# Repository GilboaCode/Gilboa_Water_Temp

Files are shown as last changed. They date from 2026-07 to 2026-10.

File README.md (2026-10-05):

Git and GitHub are used on all files within Gilboa_Water_Temp. After a file is modified:

Save changes to your local directory (your directory should be identical to the one above).

Stage all files.

Commit the files with a message.

Within GitHub, select the “Release” function.

Enter a tag name of the next release number (i.e. Release_4).

Enter a release name of the “release number – Receiver version number – Sender version number” (i.e.  “Release 4 - Receiver v1.3.02 - Sender v1.2.03”).

Attach the binaries (firmware.bin) for the Receiver and Sender. Renaming them with their corresponding target (Receiver_firmware.bin and Sender_firmware.bin).

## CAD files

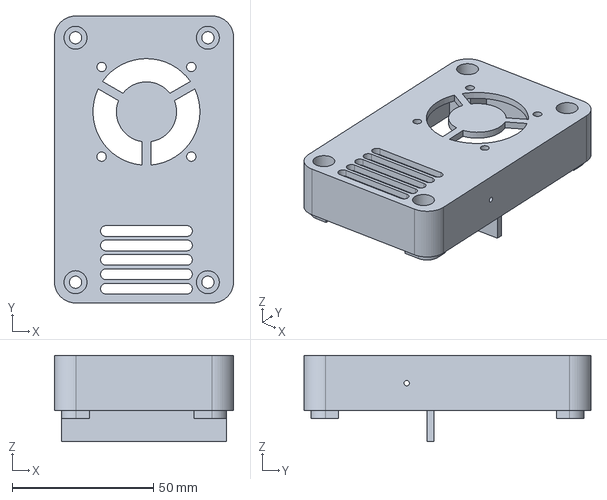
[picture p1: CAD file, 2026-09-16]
Freecad/ Receiver/Receiver.FCStd
63.5 x 101.6 x 30.4 mm

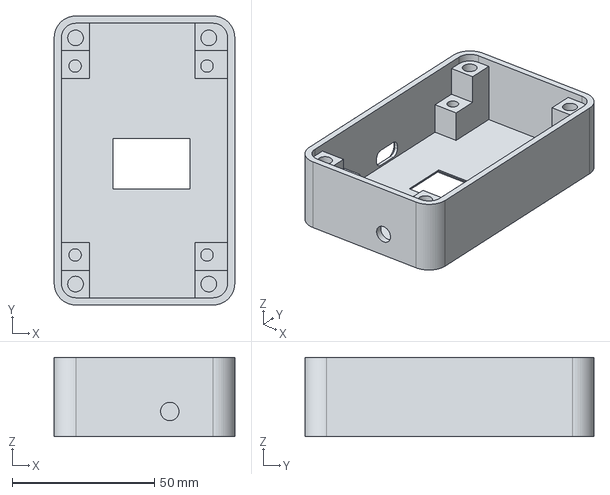
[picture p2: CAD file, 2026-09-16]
Freecad/ Receiver/Step Files/Receiver-Case.step
63.5 x 101.6 x 27.9 mm

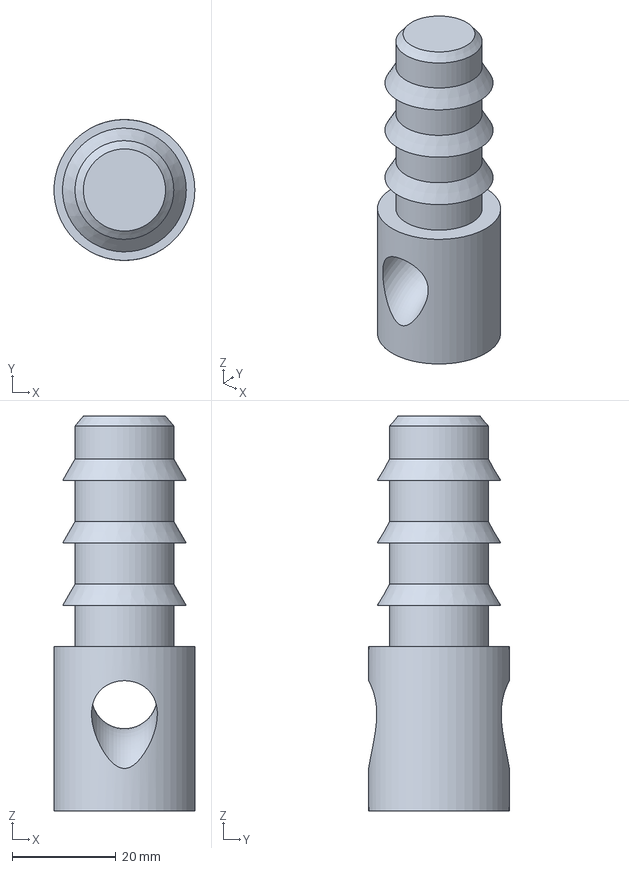
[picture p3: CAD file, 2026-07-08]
Freecad/Barbed_End_Cap_With_Hole/Barbed_End_Cap_With_Hole.FCStd
27.2 x 27.2 x 76.2 mm

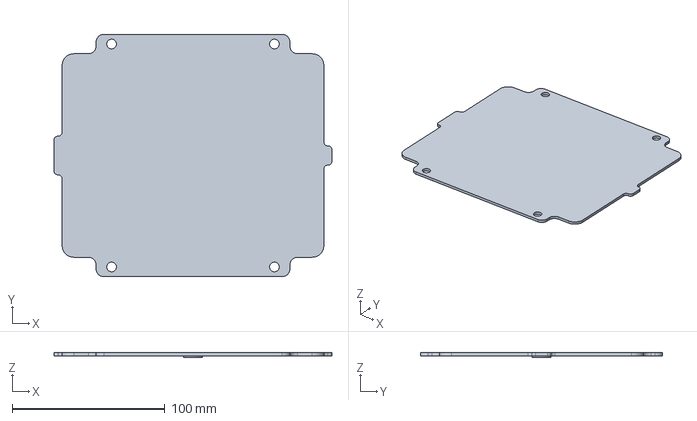
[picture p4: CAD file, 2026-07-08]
Freecad/Sender/Sender Case.FCStd
182.1 x 158.8 x 3.00 mm

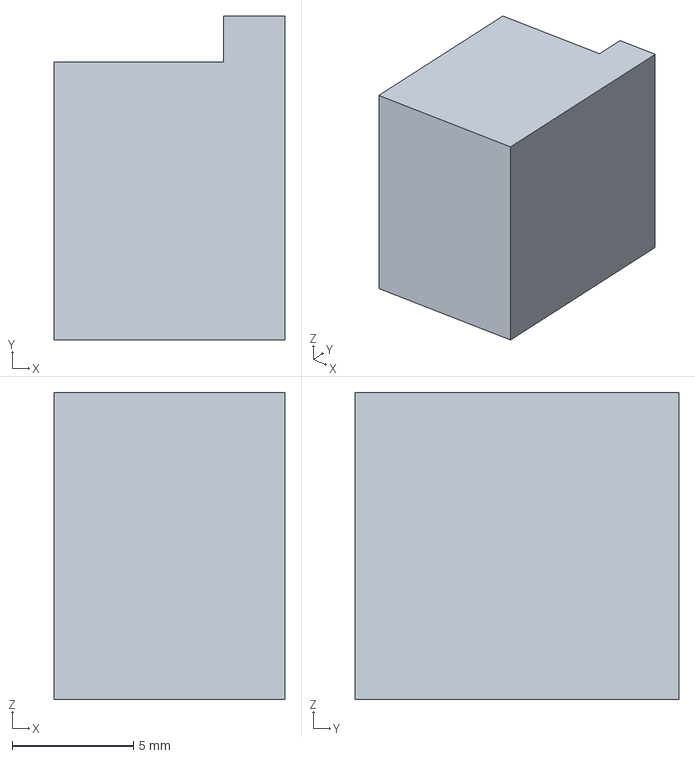
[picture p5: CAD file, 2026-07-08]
Freecad/Solar_Charger_Board_Standoff/Solar_Charger_Board_Standoff.FCStd
9.53 x 13.4 x 12.7 mm

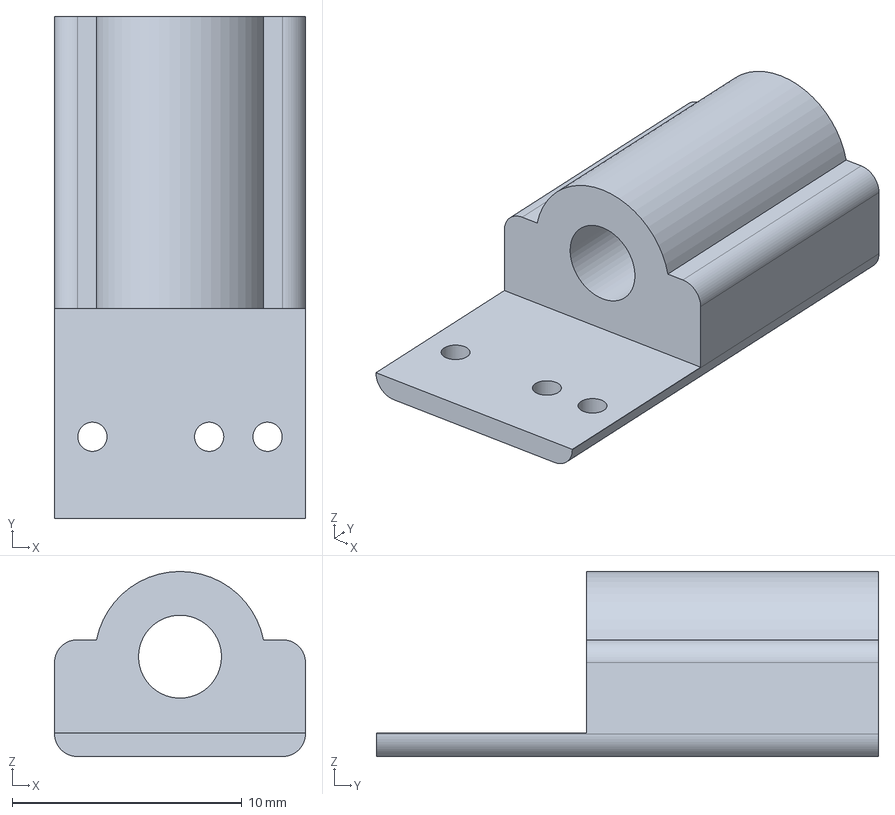
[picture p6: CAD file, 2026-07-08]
Freecad/Transducer_Tube/Transducer_Tube.FCStd
10.9 x 21.8 x 8.05 mm

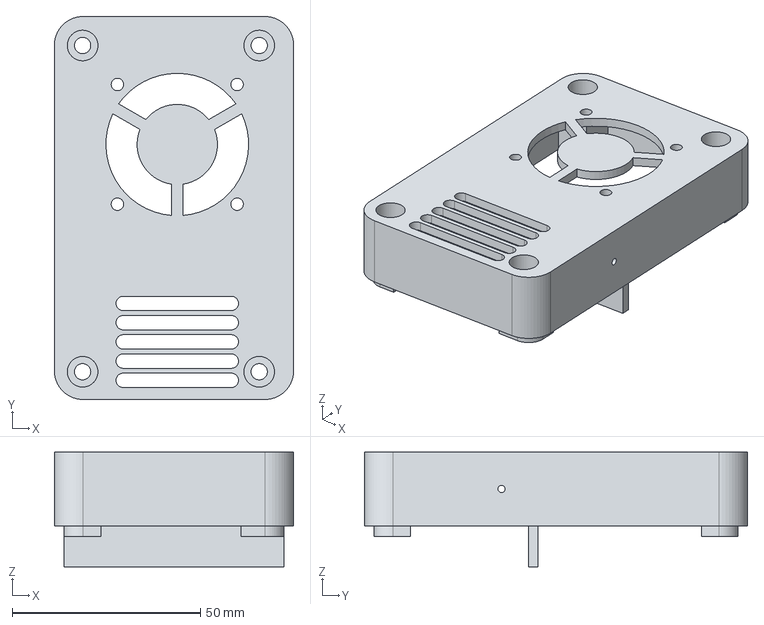
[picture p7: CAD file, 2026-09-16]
Freecad/ Receiver/Step Files/Receiver-Back with Fan.step
63.5 x 101.6 x 30.4 mm

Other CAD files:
Freecad/ Receiver/Step Files/Receiver-Back with Fan.3mf

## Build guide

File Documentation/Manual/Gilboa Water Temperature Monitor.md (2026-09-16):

# Gilboa Water Temperature Monitor

## Receiver Program Structure

```mermaid
flowchart TD
   c((LoRa Recieve interupt))-->d[[LoRa data receive handler]]

   e(CORE 0)-->f[[LoRaTask \nhandle all LoRa processing]]
   e-->g[[System Support \nWiFi, Bluetooth,FreeRTOS scheduler]]

   h(CORE 1)-->i[[Loop]]
   h-->j[[ProcessTask]]
```

## RECEIVER

### Setting up the WiFi Connection of the Receiver

1. Power up the Receiver.
2. If the Receiver has not been given an IP address from the Server, a screen will appear on the Receiver display. The last line will show the IP address the Receiver is using for it's local AP IP address. Record this address.
3. On a PC that is already connected to the WiFi network, change the WiFi connection to the Receiver temporary WiFi SSID **"WaterGaugeReceiver"** with the password:

   ```
   password123
   ```

4. In a browser window on a PC, enter this local AP IP address and a WiFi Manager screen will appear.

5. Press **Configure WiFi**.
6. If a list of networks is displayed:
   - Select the appropriate network.
   - Enter the SSID and password.
   - Save the settings.
7. Once the Receiver accepts the new network credentials, it will obtain an IP address from the selected network.
8. The assigned IP address will be displayed on the Receiver display.

---

### WiFi Reset Button

A WiFi reset button is located on the back of the Receiver.

To reset:

1. Insert a small tool (such as a toothpick) through the access hole.
2. Press until the display indicates that a WiFi reset has occurred.
3. Repeat the **Setting up the WiFi Connection of the Receiver** procedure above.

---

# Water Detected Alarm

The temperature probes are located inside a sealed vinyl tube extending from the surface to **130 feet** underwater.

The tube keeps the electronics dry.

At the bottom of the tube are two water sensors:

- **Lower sensor** — warning sensor
- **Upper sensor** — final alarm sensor (approximately 2 inches above the lower sensor)

When water reaches either sensor:

1. The sensor notifies the Sender located at the surface.
2. During its normal wake-up cycle the Sender transmits the alarm to the Receiver.
3. The Receiver sends an email or text message to every address listed in the **CONFIG** screen.

---

## Sending Text Messages by Email

Use the following email-to-SMS gateway addresses.

| Carrier | Address |
|---|---|
| AT&T | `1234567890@txt.att.net` |
| Verizon | `1234567890@vtext.com` |
| Verizon (messages over 160 characters) | `1234567890@vzwpix.com` |
| T-Mobile | `1234567890@tmomail.net` |
| Sprint | `1234567890@messaging.sprintpcs.com` |

---

# Sender and Receiver Communication

After waking from sleep, the Sender performs the following sequence.

## 1. Send Temperature

Format

```text
T,<thermocouple ROM>,<temperature °F>
```

Example

```text
T,28 DB A7 B1 00 00 00 5E,37.2
```

---

## 2. Delay

```
200 ms
```

---

## 3. Send Sender Status

Format

```text
D,<battery voltage>,<version>,<minutes asleep>,<sleep setpoint>,
<OLED enabled>,<reserved>,<bottom water sensor>,<top water sensor>
```

Example

```text
D,4.08,v1.2.01,10,0,0,0,N,N
```

---

## 4. Delay

```
200 ms
```

---

## 5. Send Complete Command

```text
C
```

---

## Receiver Response

The Receiver replies with:

```text
V,<sleep time>,<OLED disable>,<debug>
```

Example

```text
V,20,0,0
```

---

# Water Detection Email Recipients

If either of these values is received as **Y**:

- Water detected at bottom pins
- Water detected at top pins

the Receiver immediately sends notifications to every recipient in the **Water Detection Email Recipients** list on the configuration screen.

---

# Thermocouple Failure Detection

## Individual Sensor Failure

If a thermocouple fails but the OneWire bus is still operating, that thermocouple reports a **negative temperature**.

---

## OneWire Bus Failure

If the OneWire communication bus fails:

- No thermocouples can be read.
- The Receiver sends a fault message to the primary contact.
- The message reports that the **OneWire bus has faulted**.
- When the fault is corrected, another message is sent containing the restored temperatures.

---

# Telegram Setup

Install the free Telegram application.

Search for and connect to:

```
Gilboa_WaterTemp_bot
```

This allows monitoring the Receiver remotely instead of using the local WiFi interface.

---

## Telegram Commands

### `/status`

Displays:

- Receiver IP address
- Sender temperatures (air temperature plus every 10 ft)
- Sender battery voltage
- Sender version
- Sender CPU temperature
- Sender watchdog counter (current/previous)
- Sender watchdog enabled state
- Sleep timer status
- Receiver version
- Receiver CPU temperature
- Water detection status
- HTTP status code from the last POST request
- Sender OLED mode
- Sender debug mode

---

### `/rom`

Displays ROM addresses of every thermocouple.

---

### `/debug-on`

Enable Sender debug mode.

---

### `/debug-off`

Disable Sender debug mode.

---

### `/WDT-on`

Enable Receiver watchdog timer.

---

### `/WDT-off`

Disable Receiver watchdog timer.

---

### `/ota`

Display OTA partition information.

---

### `/_UPDATE`

Downloads and installs the latest firmware from GitHub.

---

### `/_RESET`

Reset the Receiver.

---

### `/help`

Display safe commands.

---

### `/start`

Same as `/help`.

---

### `?`

Same as `/help`.

---

### `/superhelp`

Displays every available command.

---

## Debug Receiver

Ground **GPIO 4** when using the debugging Receiver hardware.

This changes the Telegram bot name to:

```
Gilboa_WaterTemp_Debug_bot
```

allowing debugging without interfering with the production Receiver.

---

# Uploading New Programs to the Sender (WiFi OTA)

1. Be within WiFi range of the Sender.
2. Move the magnetic switch dongle from its storage position to the active position beneath the solar panel.
3. Connect to WiFi:

```
SSID: Gilboa_Sender
Password: Gilboa_Sender
```

4. Open:

```
http://192.168.4.2/update
```

5. Select **Choose File**.
6. Select the desired `.bin` firmware.
7. Press **Update**.
8. The Sender uploads the firmware and automatically reboots.
9. WiFi disconnects during reboot.
10. Move the magnetic switch back to its storage position.

---

# Uploading New Programs to the Receiver Using Android (USB)

Requirements:

- Android device
- ESPFlash application
- USB-C to USB-C cable

## Determine the Active OTA Slot

1. Open Telegram.
2. Connect to:

```
Gilboa_WaterTemp_bot
```

3. Run:

```
/ota
```

4. Note:

- Running partition
- Slot
- Offset

Typical offsets:

```
0x10000
0x340000
```

---

## Flash Firmware

1. Connect the USB cable.
2. Open ESPFlash.
3. Select the **Flash** icon.
4. Choose the firmware `.bin`.
5. Enter the OTA offset.
6. Select the ESP32 device.
7. Set baud rate:

```
115200
```

8. Upload.

ESPFlash can also monitor the serial output using the **Monitor** button.

---

# Uploading New Programs to the Receiver Using GitHub

Remote firmware updates can be performed through Telegram.

1. Connect to:

```
Gilboa_WaterTemp
```

2. Send:

```
/_UPDATE
```

The Receiver will:

1. Download `Receiver_firmware.bin`
2. Flash the firmware
3. Restart automatically

---

# GitHub Repository

Repository name:

```
Gilboa_Water_Temp
```

Directory structure:

```text
Documentation/
Freecad/
KiCAD/
Visual_Studio_Code/
```

| Directory | Contents |
|---|---|
| Documentation | Documentation |
| Freecad | 3D printable designs |
| KiCAD | Schematics |
| Visual_Studio_Code | Sender and Receiver C++ source code |

---

# Creating a New Release

After modifying files:

1. Save changes.
2. Stage all files.
3. Commit with a commit message.
4. In GitHub select **Release**.
5. Create a new tag.

Example:

```text
Release_4
```

6. Enter a release name.

Example:

```text
Release 4 - Receiver v1.3.02 - Sender v1.2.03
```

7. Attach the firmware binaries:

- `Receiver_firmware.bin`
- `Sender_firmware.bin`

Duplicate firmware.bin and rename the uploaded binaries to match these filenames before publishing the release.

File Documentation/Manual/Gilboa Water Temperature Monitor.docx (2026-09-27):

Gilboa Water Temperature Monitor

RECEIVER

Receiver Configuration Data BACKUP and RESTORE

The configuration variables of the Receiver can be backed up with a terminal connected to the USB port.

To back up the data:

- Enter the command BACKUP on a terminal connected to the USB port of the Receiver. There will be no echo of the typed in characters. No need for a return.
- The ESP32 will display all the configuration variables.
- Highlight and copy the information inclusive to the text “ESP32_NVS_BACKUP_V1” and “ESP32_NVS_BACKUP_END”
- Save this in a txt file.

To restore the data to the Receiver:

- Open the desired saved configuration file that was saved through a previous BACKUP command.
- Highlight and copy the information of this file, inclusive of the text “ESP32_NVS_BACKUP_V1” and “ESP32_NVS_BACKUP_END”.
- Enter the command RESTORE on a terminal connected to the USB port of the Receiver. There will be no echo of your typed characters. No need for a return.
- Paste the copied text into the terminal.

SENDER

SENDER and RECEIVER Communication

The SENDER will wake up after sleep time and sample the thermocouples , then perform the following sequence of events:

- Send the temperatures
  - T,<ROM address of thermocouple>,<thermocouple temperature (x.x) in degrees F>
  - i.e. T,28 DB A7 B1 00 00 00 5E,37.2
- Delay 200 msec.
- Send the SENDER data
  - D,<SENDER battery voltage (volts)>,<SENDER software version number>,<SENDER current time asleep (min)>,<SENDER sleep time setpoint (min)(0=default of 30 min.)>, <SENDER OLED (display) active flag>, <Debug active flag setpoint>, <Water detected at the bottom pins (Y,N)>, <Water detected at the top pins (Y,N)>
  - i.e. D,4.08,v1.2.01,10,0,0,0,N,N
- Delay 200 msec.
- Send the complete command.
  - C

The RECEIVER will then respond:

- Send the setpoint variables to the SENDER
  - V, <Sleep time setpoint (min.)>, <OLED disable setpoint flag (0,1)>, < Debug setpoint flag (0,1) >
  - i.e. V,20,0,0

Water Detected Alarm

The temperature probes are located inside a vinyl tube extending from the surface down to 130 feet in the water. The tube is sealed from the water at the bottom. The purpose of the tube is to keep the electronics dry. Inside the tube at the bottom there are two water sensors that monitor if there is a leak within the tube. The bottom water sensor is the 1st warning sensor, two inches above the bottom sensor is the final alarm sensor. When water is detected on either sensor there will be a signal sent to the Transmitter unit located at the surface, which in turn upon normal wake-up scan will send a message to the Receiver located inside the office. The Receiver will then send an E-mail or a text to all addresses on the list in the CONFIG screen (“Water Detection Email Recipients”).

The format for sending a text message should follow the following address format for the different cellular services:

AT&T: 1234567890@txt.att.net

Verizon: 1234567890@vtext.com

Verizon (longer than 160 characters): 1234567890@vzwpix.com

T-Mobile: 1234567890@tmomail.net

Sprint: 1234567890@messaging.sprintpcs.com

Water Detection Email Recipients

When a value of “Y” is received for the values of “Water detected at the bottom pins” or “ Water detected at the top pins” from the SENDER, the RECEIVER will initiate a message transmission to the recipients in the “Water Detection Email Recipients” list on the config screen.

Thermocouple Failure Detection

When a thermocouple fails and the “one_wire” communication line is still operational the temperature value for that thermocouple will be a negative value.

When the failure corrupts the “one_wire” communication line, the controller can not read any of the thermocouples. This failure is detected and will send a message to the primary contact. The message will state that the “one_wire” has faulted. When the fault has been corrected another message will be sent showing the temperatures of the thermocouples.

Telegram Steup

In order to get the latest information from the Receiver on Telegram instead of from the Receiver’s local WiFi connection, you need to install the free app “Telegram”. Once installed search for the chat name of “Gilboa_WaterTemp_bot” and connect.

The following are valid commands and reponces:

/status

Last update time of temperatures from the Sender

Sender Temperature data (Air Temp + every 10 ft)

Sender Version

Sender CPU Temperature

Sender Battery Voltage

Sender WDT counter (current/previous)(watch-dog-timer)

Sender WDT Enabled state

Sleep timer status (running time / set sleep time for sender)

Receiver Version

Receiver CPU Temperature

Water detection status at lower sensor and upper sensor

HTTP Status Code of last POST request to postUrl

Display Mode of Sender (OLED on/off)

Debug Mode of Sender (on/off)

/rom ROM addresses of all the Thermocouples

/disp_on Turn on the Receiver display (the display will turn off after a time delay).

/debug-on Command to enable debug mode on the Sender

/debug-off Command to disable debug mode on the Sender

/WDT-on Receiver’s Watchdog timer on

/WDT-off Receiver’s Watchdog timer off

/ota Show OTA partition information for Receiver

/_UPDATE Command to upload firmware.bin on the Gilboa Github site to the Receiver

/_RESET Reset the Receiver (not shown in help)

/_NETWORK Show the Receiver Network info

/help Command to show safe commands (shown in green)

/start same as /help

? Same as /help

/superhelp Command to show ALL available commands. (shown in green and in blue)

When using the Debugging Receiver hardware, short to ground the GPIO pin 4. This will allow the debugging receiver to use the Telegram bot name of “Gilboa_WaterTemp_Debug_bot” Allowing the debugging Receiver not to interfere with the Telegram messages from the on-site Receiver at Gilboa.

INSTALLING NEW PROGRAMS IN THE ESP32

Uploading New Programs to the Sender by WiFi

To upload a new program to the Sender with out having to disassemble the unit to get at the USB connector, you can use the OTA by WiFi feature programmed into the Sender code.

- Make sure you are within the WiFi proximity of the Sender unit.
- Move the magnetic switch dongel from it’s storage location to the engage location (under the solar panel). This will activate the Server code on the Sender unit.
- Connect to the Sender unit by WiFi by selecting the SSID of “Gilboa_Sender” with the password of “Gilboa_Sender” on your laptop or phone.
- From a web browser, go to the site “192.168.4.2/update”, to connect to the Sender unit.
- Select the “Choose File” button, then select the desired “.bin” file.
- Select the “Update” button. This will upload the selected .bin file and reset tthe Sender. You will loose the WiFi connection when the Sender is reset.
- Your new program has now been installed on the Sender unit.
- Move the magnetic switch dongel back to it’s storage position.

Uploading New Programs to the Receiver by USB using an Android

To upload a new program to the Receiver using the USB connector using an Android running the program ESBFlash.

- Before any binary file can be downloaded to the Receiver by USB, you need to know which slot is currently holding the Receiver program (slot 0 or slot 1). They each have their own starting address. Run the Telegram application on the Android.
- Connect to “Gilboa_WaterTemp_bot.
- Enter the command “/ota”.
- This will display the “Running partition” and it’s associated slot.
- This slot will have an offset (10000 or 340000). Remember this offset.
- Connect a USB-C male to USB-C male cable between the Receiver and the Android.
- Start the ESBFlash program on the Android.
- Select the “Flash” icon at the bottom left hand side of the Android screen.
- Select the bin file to upload by pressing the “+” nect to “Firmware File”, and choice the file to upload.
- A popup box will appear asking for the address where this bin file is to be uploaded to on the Receiver. Enter the offset that was determined above..
- Another popup box will appear as to what device is this bin file to be uploaded to. There will only be one device, select it.
- For the baud rate, enter 115200.
- Select the upload icon.

The ESPFlash application can also monitor the serial USB line by selecting the “Monitor” icon at the bottom right hand side of the Android screen.

Uploading New Programs to the Receiver by Github

UploadIg a new program to the Receiver remotely by using Github and Telegram allows the user to upload to and flash the Receiver with the latest “Released” program.

- From theTelegram application, connect to “Gilboa_WaterTemp”.
- Enter the command “/_UPDATE”.
- This command will upload the program Receiver_firmware.bin from the “Gilboa_Water_Temp” repository, flash and then reset the ESP32.

The location of the “Receiver_firmware.bin” file is in the Github latest release of the Receiver.

Modifing the files in the GitHub Repository

The name of the Repository is “Gilboa_Water_Temp”. The directoy structure is:

Documentation - All documentation

Freecad - Freecad files for all 3d printed objects

KiCAD - Schematics for all electronic circuits

Visual_Studio_Code - All C++ code for the Sender and Receiver

Git and GitHub are used on all files within Gilboa_Water_Temp. After a file is modified:

- Save changes to your local directory (your directory should be identical to the one above).
- Stage all files.
- Commit the files with a message.
- Push to GitHub
- Within GitHub, select the “Release” function.
  - Enter a tag name of the next release number (i.e. Release_4).
  - Enter a release name of the “release number – Receiver version number – Sender version number” (i.e. “Release 4 - Receiver v1.3.02 - Sender v1.2.03”).
  - Attach the binaries (firmware.bin) for the Receiver and Sender. Renaming them with their corresponding target (Receiver_firmware.bin and Sender_firmware.bin).

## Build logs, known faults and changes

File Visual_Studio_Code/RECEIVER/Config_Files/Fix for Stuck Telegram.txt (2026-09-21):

Commands to kill WEBHOOKs

curl "https://api.telegram.org/bot8328269756:AAGSF-JlY4pAeiHQWRxxzP-bReZdUqOJZxY/deleteWebhook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"
curl "https://api.telegram.org/bot8328269756:AAGSF-JlY4pAeiHQWRxxzP-bReZdUqOJZxY/getWebhookInfo"

curl "https://api.telegram.org/bot8820302613:AAHUGMsmcHJNaG1YZnqkC-uzV6Y8-I1HwvA/deleteWebhook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"
curl "https://api.telegram.org/bot8820302613:AAHUGMsmcHJNaG1YZnqkC-uzV6Y8-I1HwvA/getWebhookInfo"

// Gilboa_WaterTemp_Debug_bot - "8328269756:AAGSF-JlY4pAeiHQWRxxzP-bReZdUqOJZxY"
// Gilboa_WaterTemp_bot - "8820302613:AAHUGMsmcHJNaG1YZnqkC-uzV6Y8-I1HwvA"

NO WEBHOOKs
 curl "https://api.telegram.org/bot8328269756:AAGSF-JlY4pAeiHQWRxxzP-bReZdUqOJZxY/getWebhookInfo"
  {
    "ok":true,
    "result":{
       "url":"",
       "has_custom_certificate":false,
       "pending_update_count":0,
       "allowed_updates":["message","edited_message","channel_post","edited_channel_post"]
     }
  }

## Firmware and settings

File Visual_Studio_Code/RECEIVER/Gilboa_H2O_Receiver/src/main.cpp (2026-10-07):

// Receiver -- v1.3.09
//  * Added a new command (/_HISTORY) to the Telegram bot to display the history of the Receiver. 
//    The times of the last received packets were received from the Sender, and when the receiver was reset.
//  * Fixed the Get Date and Time of last update.
//  * After 60 attemts to connect to WiFi, the Receiver will reset itself. This is to prevent the Receiver from being stuck in 
//    a loop trying to connect to WiFi and not being able to recover.
//  * Added a third WiFi connection when the Gilboa or Klopping network can not connect, Jeff's Android Hot Spot.
//  * Added WiFi connection diagnostics to the OLED display to show which network the Receiver is trying to connect to. 
//
// Receiver -- v1.3.08
//  * Added Daylight savings time (DST) detection to the NTP time client to determine if the current time is in DST or not. 
//    This is to allow for the correct time to be displayed on the OLED display and on the Telegram /status command. 
//    The time is displayed in UTC and the offset is calculated based on the current date and time. The offset is then used 
//    to set the time client to the correct time zone.
//  * Added a new command to the configuration web interface to set the DST mode. The selection is made from a dropdown menu.
//    The selection is 0 - No DST, 1 - DST Auto, 2 - DST all year. The default is 1 - DST Auto. The selection is saved in NVS 
//    and loaded on startup.
//
// Receiver -- v1.3.07
//  * Added a time of last update to be displayed on /status command in Telegram.
//
// Receiver -- v1.3.06
//  * Added a new command (/_NETWORK) to the Telegram bot to seperate the network information of the Receiver from the status
//    command. It will display the SSID, IP address, and MAC address of the Receiver. This is to help with determining what 
//    Network the Receiver is connected to and its network details.

// Receiver -- v1.3.05
//  * Added the wifi network name to the Telegram /status command to show which network the Receiver is connected to. 
//    This is to help with determining what Network the Receiver is connected to.

// Receiver -- v1.3.04
//  * Modified the code to turn off the OLED after 30 seconds after power up of the Receiver. This is to prevent the OLED from being on 
//    for long periods of time and heating up the Receiver.
//  * Added new switch at GPIO19 called activateOLEDpb to activate the OLED display on the Receiver for 30 seconds.
//  * Added a command to the Telegram bot to activate the OLED display on the Receiver for 30 seconds (/disp_on)).
//  * Added three command to USB Terminal to BACKUP, RESTORE and PING the NVS data to a file on the SD card. This is to allow 
//    for easy backup and restore of the Receiver configuration data.
//  * Made the SSID and Password fixed in code. On power up it selects between two SSID's and passwords based on the 
//    state of Debug mode input (GPIO4). If GPIO4 is shorted to ground it will use the debug SSID and password, if not 
//    it will use the production SSID and password. The server will select the IP address. This address will show on the
//    OLED display and on the Telegram /status command. The IP address is fixed in code for both the debug and production 
//    SSID's.   

// Receiver -- v1.3.03
//  * Followed the splitting of the "D" packet from the Sender to "D" excluding water detect and "W" for water detect. 
//    Correcting the problem of n/a for water detect due to data being sent to receiver before 1-wire power being turned on.
//  * Added distinction between failed all LORA reception and failed just t/c reception (with messages sent to recipients).
//  * Instead of sending seperate e-mails out, code has been changed to send one e-mail with all listed recipients in as "cc"ed.
//  * On LoRa setup failure, the code will now wait 10 seconds and then restart the ESP32 instead of hanging in a while loop. 
//    This allows for a more robust recovery from LoRa module issues.
//  * In Telegram /status printout, moved Sender version before Sender battery voltage to make it easier to read and understand the 
//    information being displayed.
//
// Receiver -- V1.3.02
//  * Added code to monitor the timing of the "D" packet from the Sender to implement a watchdog. 
//    When the Sender wakes up it will send a "D" packet to the Receiver first, before turning on the aux 3 volts that powers up the 1-wire board.
//    If the Receiver does not receive a "D" packet from the Sender within 60 minutes, it will assume that the Sender is not 
//    functioning and will send an alert to the operator via email (if configured).
//    This will determine if the loss of temperature readings is due to a failure of the 1-wire board or a failure of the Sender itself.
//    A flag is also added to signify the the Receiver has seen the Sender at least one time to handle the power up sequence of the Receiver and Sender.
//    This flag is used to prevent false alerts on the first boot of the Receiver when the Sender has not yet sent a "D" packet.
//    The function of this change is to determine if no t/c data is due to flooded t/c tube or an Sender ESP32 problem.
//    There is a disable flag to disable the watchdog if the operator does not want to use this feature. 
//    The disable flag is settable by the operator and is settable in the Telegram page.
//  * Changed the name of the GitHub download file to Receiver_firmware.bin to distinguish it from the 
//    Sender_firmware.bin file. The Receiver_firmware.bin file is in the "latest" folder of the GitHub repository.
//
// Receiver -- V1.3.01
//  * Modified the location of the firmware.bin to be in the "latest" folder of the GitHub repository to allow for future versioning of the firmware.
//
// Receiver -- V1.3.00
//  * Added a new command (/_UPDATE)to the Telegram bot to update the Receiver remotely. It will download and install the latest firmware from the GitHub repository 
//
// Receiver -- V1.2.05
//  * Added a new command (/_RESET)to the Telegram bot to reset the Receiver remotely. The command is /reset and it will restart the Receiver when issued.*
//  * Moved all the LoRa xmitt/rcve interrupts to a single core.
//
// Receiver -- V1.2.04
//  * Changed the reception of LORA commnication from polling to interrupt based.
//  * Hide the "debug-on" and "debug-off" commands from the Telegram help display, commands are still active.
//
// Receiver -- V1.2.03
//  * Changed text on web site display from "Battery" to "Sender Battery" to clarify that this is the battery voltage of the Sender, not the Receiver. 
//
// Receiver -- V1.2.02
// * Added Telegram Bot integration for:
//  /status command
//      Receiver IP address
//      Sender Temperature data (Air Temp + every 10 ft if detected)
//      Sender Battery Voltage
//      Sender Version
//      Receiver Version
//      Water detection status at top and bottom sensors
//      HTTP Status Code of last POST request to postUrl
//      Sleep timer status (running time / set sleep time for sender)
//      Display Mode of Sender (OLED Active)
//      Debug Mode of Sender
//  /rom  Display the thermocouple ROM addresses
//  /debug-on command to enable debug mode on the Sender 
//  /debug-off command to disable debug mode on the Sender
//  /help command to show available commands
//  * Added Sender and Receiver CPU temperature reading
//  * Added a Debug Telegram bot tolken when a second receiver is being used to debug  new code on the Sender without interfering with the main Receiver bot. 

// Receiver - v1.2.01
// * Added water detection status to the OLED display and the local web page.
// * Added email alert functionality to notify the operator when water is detected at the top or bottom sensor. The email recipient can be configured on the web page.
// *    Gilboa Water Temp project Gmail account
// *    GilboaWaterTemp@gmail.com
// *    Login Password: 87Gil2026 (only for manual login)
// *    App Password: efocbnzvxhcfwngx (app password for this project)
// * Added NTP client to get real time for email alerts and web page display. Time is displayed in UTC.
// * Added ability to configure multiple recipient emails (up to 6) on the web page. These are saved in NVS and loaded on startup.
// * Added ability to configure the sender email and password (app password) on the web page. These are saved in NVS and loaded on startup.

// *

//Receiver - v1.2.00
// * Receive temps from string T,ROM address,temperature
// * Receive data from string D,battery voltage,sender_version,SLEEP_MINUTES
// * After data received from Sender send the string  V,aux_sleep_minutes,OLED_flag_from_receiver,debug_flag_from_receiver
// * Added flag in the Receiver to tell the Sender to enter debug mode.
// * Added the flag to tell the Sender to enter OLED active mode.
// * Added a color change to RED in the "Position" field on the config screen when a thermocouple is not detected.
// * Added red color change to the submit buttons on the config page when there are unsaved changes.
// * Added Sleep time counter and setpoint on the main web page.


// Receiver - v1.1.01 
// • Display "Looking for WiFi" on power up
// * On the local web page display the version number of the Receiver
// * Added HTTP POST for link to web server
// * Added http status code to the OLED display and on the Config web page
// * Removed the 15 seceond refresh rate on the config web page to prevent interference with form submission
// * On the local web page display the version number of the Sender (FUTURE)
// * Added flag to tell the Sender to update every10 seconds for testing (FUTURE)

// Receiver - v1.0.07 (FINAL – GRAPH FIXED + EVERYTHING ELSE PRESERVED)
// • Physical WiFi reset: GPIO45 → GND only
// • No web reset page
// • All temperatures show correctly (including Air Temp)
// • Perfect working temperature vs depth graph

#define receiver_version "v1.3.09"

#include <RadioLib.h>
#include <SPI.h>
#include <U8g2lib.h>
#include <Wire.h>
#include <WiFi.h>
#include <WiFiManager.h>
#include <WebServer.h>
#include <Preferences.h>
#include <HTTPClient.h>
#include <ESP_Mail_Client.h>
#include <ctype.h>
#include <string.h>

#include <NTPClient.h>
#include <WiFiUdp.h>

#include <HTTPUpdate.h>
#include "esp_ota_ops.h"
#include "esp_partition.h"
#include <esp_image_format.h>


// ---------------------------------------
// ---------- IP configurations ----------
// ---------------------------------------

// ---------- WiFi credentials Gilboa Guest ----------
String ssid_pd     = "Gilboa Guest";
String password_pd = "DiveGilboa";

// ---------- Alternate 1 WiFi credentials Gilboa Office ----------
//String ssid_alt1     =  "Office";
String ssid_alt1     =  "OOffice";
String password_alt1 = "FullTank#0412";

// ---------- Alternate 2 WiFi credentials Jeff's Android Hotspot ----------
String ssid_alt2     = "Galaxy S26 Ultra BF31";
String password_alt2 = "z2knwvh3bckrhgs";

// Debug WiFi credentials for testing
String ssid_db     = "k-net";
String password_db = "5f6d35440b39983686af09321d";



// ---------- WiFi credentials ----------
String ssid     = "";
String password = "";

// Telegram Bot
#include <WiFiClientSecure.h>
#include <UniversalTelegramBot.h>
// Gilboa_WaterTemp_Debug_bot - "8328269756:AAGSF-JlY4pAeiHQWRxxzP-bReZdUqOJZxY"
// Gilboa_WaterTemp_bot - "8820302613:AAHUGMsmcHJNaG1YZnqkC-uzV6Y8-I1HwvA"
#define Telegram_Debug_Mode_Pin 4 // Short to ground to enable the Telegram tolken of Gilboa_WaterTemp_Debug_bot tolken
#define BOT_TOKEN "8820302613:AAHUGMsmcHJNaG1YZnqkC-uzV6Y8-I1HwvA"
#define BOT_TOKEN_Debug "8328269756:AAGSF-JlY4pAeiHQWRxxzP-bReZdUqOJZxY"
String Active_Bot_Token = BOT_TOKEN; // Default to the main bot token, can be changed to the debug bot token if the debug mode pin is shorted to ground 
WiFiClientSecure secured_client;
UniversalTelegramBot bot(Active_Bot_Token, secured_client);



// Gmail SMTP Server Settings
#define SMTP_server "smtp.gmail.com"
#define SMTP_Port 465
String sender_email = "GilboaWaterTemp@gmail.com";
String sender_password = "efocbnzvxhcfwngx"; // App password for this project, not the actual email password
#define Recipient_name ""
SMTPSession smtp;


#define LORA_MOSI 10
#define LORA_MISO 11
#define LORA_SCK  9
#define LORA_CS   8
#define LORA_RST  12
#define LORA_BUSY 13
#define LORA_DIO1 14    // Interupt pin for LoRa module, used to detect when a packet is received
#define LORA_FREQ 915.0f

#define OLED_ON_PB 19 // Short to ground to activate the OLED display on the Receiver for 30 seconds
int OLED_On_Timer_Counter = 0; // Timer to track how long the OLED display has been on, in seconds
bool OLED_On_Flag = false; // Flag to indicate if the OLED display is on or off
bool displayOnCommand = false; // Flag to indicate if the display has been commanded to turn on

#define RESET_PIN 45
#define Display_On_Pin 36 //Set GPIO36 LOW before initializing the OLED display (display.begin())
bool resetTriggered = false;

U8G2_SSD1306_128X64_NONAME_F_HW_I2C u8g2(U8G2_R0, 21);
WebServer server(80);
Preferences prefs;

// Graph Y-axis (saved in NVS)
float graphMinY = 32.0f;
float graphMaxY = 90.0f;

String  Recipient_email = "jeffklopping@gmail.com"; // Default recipient email, can be updated on the web page and saved in NVS

String postUrl = "http://jsonplaceholder.typicode.com/test"; // Default POST URL for testing, can be updated on the web page and saved in NVS
int httpCode=0;

// Setup the handle for the two code tasks
TaskHandle_t task0Handle;
TaskHandle_t task1Handle;
// Create the radio object
SX1262 LoRa = new Module(LORA_CS, LORA_DIO1, LORA_RST, LORA_BUSY);
// Global variables for interupt flag
bool shutUpImTransmitting = false;
bool newPacketReceived = false; 
struct LoRaPacket // Buffer for the incomming LoRa data
{
    char text[128];
};
QueueHandle_t loraQueue;
String sendPacket;
int delayTimeBeforeVPacket = 225; // Delay between packets in milliseconds

// Global state
String SenderVersion = "N/A";
int  SenderSleepTime = 0;
String ReceiverVersion = receiver_version;

String lastSenderBatt = "N/A";
String lastRssiStr = "N/A";
unsigned long lastPacketTime = 0;
#define SLEEP_TIMEOUT_MS 20000
int sleep_time_for_sender ;

// Array for up to 6 recipient emails
String recipient_emails[6] = {
  "jeffklopping@gmail.com", "", "", "", "", ""
};

// Real time
WiFiUDP ntpUDP;
NTPClient timeClient(ntpUDP, "pool.ntp.org", 0 , 60000);  // UTC offset 0 hours, update every 60s
int hour;
int minute ;
int second ;
int year;
int month;
int day ;
int UTCoffset;
bool daylight_saving_time_flag ; // True- Enabled, False - Disabled. This is to allow the operator to turn off DST detection if the operator does not want to use this feature. The default is DST detection on. This variable is stored in NVS and is loaded on startup.
int DayLightSavingTimeMode = 0; // 0 = No DST , 1 = DST Auto, 2 = DST all year
#define packetTimeBufferSize 45
String last30PacketTimes[packetTimeBufferSize]; // Buffer of the last packet times received from the Sender
int last30PacketTimesIndex = 0; // pointer to the next index in the last30PacketTimes array to store the next packet time


// Sender Water Detector 
String water_top_detected = "N/A";
String water_bottom_detected = "N/A";
bool topWaterAlertSent = false;    // true = alert already sent for top sensor
bool bottomWaterAlertSent = false; // true = alert already sent for bottom sensor

// Timer to track running time since last packet
unsigned long runningTimer = 0;
int minCounter = 0;

// Variable to handle watchdog of Sender ESP32 to determine if the Sender is alive and functioning properly
// When a "D" packet is received move the runningDataPacketTimer to previousDataPacketTime and runningDataPacketTimer=0. 
// and save millis() in lastDataPacketTime. 
bool senderSeenFlag = false; // Flag to indicate if the Sender has been seen at least once
unsigned long lastDataPacketTime = 0.0; // Real time of the last "D" packet received from the Sender 
unsigned long previousDataPacketTime = 0.0; // Previous measuredtime between "D" packet received from the Sender 
unsigned long runningDataPacketTimer = 0; // Active running timer for "D" packets from the Sender in minutes
static bool senderFailedFlag = false; // Flag to indicate if the Sender has failed to send a "D" packet within the timeout period
bool watchdogEnableFlag = false; // Flag to indicate if the watchdog is enabled by the operator via Telegram bot command
static bool senderThermocoupleFailFlag; // Flag to indicate no t/c data in 60 min.

// Flag to send variables even on no change (startup)
bool resetVariablesFlag = false;
// Operator Variables to send to Sender
static int aux_sleep_minutes=0;
static boolean OLED_flag_from_receiver = false;
static boolean debug_flag_from_receiver = false;
// Operator variables old values for change detection
int old_aux_sleep_minutes=0;
boolean old_OLED_flag_from_receiver = false;
boolean old_debug_flag_from_receiver = false;

String uniqueRoms[14];
int uniqueRomCount = 0;

String romTable[14];
float temperatures[14];
bool romTableLoaded = false;
bool temperatureDetected[14] = {false};
bool temperatureDetectedHistory[14] = {false};
float defaultNoThermocoupleTemp = -196.6f; // Default temp when no thermocouple is connected

const char* depthLabels[14] = {
  "Air   ", "10  ft", "20  ft", "30  ft", "40  ft", "50  ft", "60  ft",
  "70  ft", "80  ft", "90  ft", "100 ft", "110 ft", "120 ft", "130 ft"
};

const int w = 600;
const int h = 300;
const int margin = 50;

// Processor temperatures
float Receiver_temp_farenheit = 0.0f;
String Sender_temp_farenheit ;

// Telegram Bot variables
bool telegramResetFlag = false; // Flag to indicate if the /reset command was received from the Telegram bot
bool telegramUpdateFlag = false; // Flag to indicate if the /update command was received from the Telegram bot
bool telegramUpdateFailedFlag = false; // Flag to indicate if the /update command failed
const char* firmwareURL ="https://github.com/GilboaCode/Gilboa_Water_Temp/releases/latest/download/Receiver_firmware.bin";
bool updateStarted = false;


// === NVS ===
void loadGraphLimits() {
  prefs.begin("graph", true);
  graphMinY = prefs.getFloat("minY", 32.0f);
  graphMaxY = prefs.getFloat("maxY", 90.0f);
  prefs.end();
}

void saveGraphLimits() {
  prefs.begin("graph", false);
  prefs.putFloat("minY", graphMinY);
  prefs.putFloat("maxY", graphMaxY);
  prefs.end();
}

// === NVS: Load/Save Email Config ===
void loadEmailConfig() {
  prefs.begin("email", true);
  Recipient_email = prefs.getString("recipient_email", "jeffklopping@gmail.com");
  prefs.end();
  Serial.print("Loaded recipient email: "); Serial.println(Recipient_email);
}

void saveEmailConfig() {
  prefs.begin("email", false);
  prefs.putString("recipient_email", Recipient_email);
  prefs.end();
  Serial.print("Saved recipient email: "); Serial.println(Recipient_email);
}
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
void loop() {
  checkHardResetPin(); // Check reset pin for resetting the wifi address
  server.handleClient(); 

  checkOLEDOnPin(); // Check OLED pin for turning on the OLED display

  //Serial.print("IP: "); Serial.println(WiFi.localIP());
  if (WiFi.status() != WL_CONNECTED) {
    Serial.println("WiFi disconnected, restarting...");
    ESP.restart(); 
  }

    handleUSBCommands();
//-------------------------

  // Update OLED with latest info (including water detection status)(if enabled)
  if (newPacketReceived == true){
    newPacketReceived = false;
    updateOLED();
    postTemperaturesToJsonPlaceholder();   // Only POST at the end
    Serial.println("Posted temperatures to HTTP endpoint");      
  }

  // Handle email message on water detected
  if ((water_bottom_detected == "Y" ) && !bottomWaterAlertSent) {
    //Serial.println("Bottom Water detected - sending email alert");
    String alertDetails = "Water Detected at: Bottom Sensor";
    sendEmailAlert("Water Detected Alert", alertDetails);
    bottomWaterAlertSent = true;
  }else{
    if (water_bottom_detected == "N" ) {
      bottomWaterAlertSent = false; // Reset alert flag when water is no longer detected
    }
  }

  if ((water_top_detected == "Y" ) && !topWaterAlertSent) {
    //Serial.println("Top Water detected - sending email alert");
    String alertDetails = "Water Detected at: Top Sensor";
    sendEmailAlert("Water Detected Alert", alertDetails);
    topWaterAlertSent = true;
  }else{
    if (water_top_detected == "N" ) {
      topWaterAlertSent = false; // Reset alert flag when water is no longer detected
    }
  }

  //Handle Telegram messages
  checkTelegram();

  // Update running timer every 30 seconds to track how long it's been since the last packet was received
  if (millis() - minCounter > 30000) {
    minCounter = millis() ;
    runningTimer = (millis() - lastPacketTime)/60000;
    runningDataPacketTimer = (millis() - lastDataPacketTime)/60000;
  }

  // Test if Sender has failed to send data for more than 60 minutes
  //    senderFailedFlag (NVS) is used to only send failed message once, reset by receiving "D" packet again
  if (watchdogEnableFlag == true){
    // Handle loss of all LORA comms
    if (runningDataPacketTimer > 60  && senderFailedFlag == false) {
      setSenderFaultFlag();
    }
    // Handle loss of just thermocouples
    if (runningTimer > 60 && senderThermocoupleFailFlag == false){
      setTCFaultFlag (); // Set the flag, show t/c values as "N/A" and send alert to addresses on list
    }
  }

  // Handle the OLED timer countdown
  if (OLED_On_Flag == true) {
    if (millis() - OLED_On_Timer_Counter > 30000) {
      OLED_On_Flag = false;
      updateOLED();
    }
  }
  delay(100);
}

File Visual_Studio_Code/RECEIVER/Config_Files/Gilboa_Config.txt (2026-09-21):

ESP32_NVS_BACKUP_V1
graph.minY=34.400002
graph.maxY=75.000000
email.recipient_email=4193042172@vtext.com
recipients.email0=4193042172@vtext.com
recipients.email1=jeffklopping@gmail.com
recipients.email2=2488954874@tmomail.net
recipients.email3=4194807632@tmomail.net
recipients.email4=
recipients.email5=
sender.email=GilboaWaterTemp@gmail.com
sender.password=efocbnzvxhcfwngx
post.url=https://gilboaquarry.com/temp_api.php?key=gilboa_temp_9f3kL2x8Qp7Zr4T
operator.aux_sleep=0
operator.oled_flag=0
operator.debug_flag=0
operator.watchdog_en=1
rom_table.0=28 DB A7 B1 00 00 00 5E
rom_table.1=28 12 C7 B4 00 00 00 C7
rom_table.2=28 A6 60 B2 00 00 00 77
rom_table.3=28 E4 57 B9 00 00 00 2D
rom_table.4=28 F0 9B B4 00 00 00 34
rom_table.5=28 48 CA BA 00 00 00 DF
rom_table.6=28 F7 6F BA 00 00 00 1D
rom_table.7=28 57 DF BA 00 00 00 0E
rom_table.8=28 04 DB BA 00 00 00 66
rom_table.9=28 D2 A5 B4 00 00 00 CA
rom_table.10=28 70 F6 BA 00 00 00 36
rom_table.11=28 57 B8 B4 00 00 00 5B
rom_table.12=28 54 4E B4 00 00 00 38
rom_table.13=28 CE A0 B4 00 00 00 3E
dst.mode=1
ESP32_NVS_BACKUP_END

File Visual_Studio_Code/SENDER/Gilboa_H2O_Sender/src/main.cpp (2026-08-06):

// Sender - v1.2.04
//  * Fixed the sending of the "D" packet to the Receiver before turning on the aux 3 volts that powers up the 1-wire board. 
//    There was another power up call before the "D" command was sent in the Setup.
//  * Added a LORA_fail_flag and one_wire_fail_flag on a failure to init the LORA or the DS2484. This prevents
//    Sending out packets to the Receiver for the remaining time of the sleep cycle, where it will try to communicate again.
//  * Split the "D" packet so as not to send the water detector status when the one-wire is not powered up.
//  * Added the "W" packet for the water detectors.
//
// Sender - v1.2.03
//  * Modified the sequence of the command from the Sender to the Receiver to implement a watchdog. The Receiver will use this
//    to indicate that the Sender is alive regardless of whether it is transmitting t/c data. 
//    When the Sender wakes up it will send a "D" packet to the Receiver first, before turning on the aux 3 volts that powers up the 1-wire board.
//    If the Receiver does not receive a "D" packet from the Sender within 2 minutes, it will assume that the Sender is not 
//    functioning and will send an alert to the operator via email (if configured).
//    This will determine if the loss of temperature readings is due to a failure of the 1-wire board or a failure of the Sender itself.
//
// Sender - V1.2.02
//  * Added Sender CPU temperature reading and transmission to Receiver on every cycle, displayed on 
//    OLED and sent to Receiver for display on web page and OLED)
//  * Added a wifi access point to allow OTA updates of the Sender firmware using the ESP2SOTA library. 
//    When the Debug Mode magnetic switch is made, the Sender will stay awake and start a WiFi access point for 
//    OTA updates. The access point is called "Gilboa_Sender" and has a password of "Gilboa_Sender".
//    The access point is configured to have a static IP address of 192.168.4.2.

// Sender - v1.2.01
// * Added Water detection - Water is detected between an open wire and the open ground wire next to it at the bottom of the sensor vinyl tube.
// * There are two water sensors, one at the bottom of the vinyl tube and one a few inches above it.
// * The sense of the water state is conveyed by two binary variables sent to the Receiver on the D, packet: water_bottom_detected and water_top_detected.

// Sender - v1.2.00
// * Send temps in string T,ROM address,temperature
// * aux_sleep_minutes,OLED_flag_from_receiver,debug_flag_from_receiver are stored in RTC memory and survive deep sleep
// * After data is sent, delay then wait for a packet from the Receiver (V,aux_sleep_minutes,OLED_flag_from_receiver,debug_flag_from_receiver)
// * Send data in string D,battery voltage,sender_version,SLEEP_MINUTES,aux_sleep_minutes,OLED_flag_from_receiver,debug_flag_from_receiver
// * Added flag in the Receiver to tell the Sender to enter debug mode (debug_flag_from_receiver)
// * Added the flag to tell the Sender to enter OLED active mode (OLED_flag_from_receiver)
// * Both flags are stored in NVS and survive deep sleep/power cycle
// * Added aux_sleep_minutes to allow changing of sleep time from Receiver
// * On first boot after power-on, default values are used and NVS is not read
// * After first boot, operator variables are loaded from NVS and saved on changes

// Sender - v1.1.01
// GPIO 2 = Debug mode - On a transition from low to high, stay awake, exit debug mode when signal is low
// Send version number to receiver 
// If a theralcouple data is missing, send -196.6 to indicate no data (future)

// Sender - v1.0.04
// GPIO 4 = OLED BLANK SWITCH
// Short GPIO 4 to GND = OLED OFF
// Open = OLED ON
// NEW: On wake-up, read ALL probes immediately (parallel conversion)
// Then send EVERY reading to receiver with NO delays
// ONLY enter sleep AFTER all readings have been sent
//

#define sender_version "v1.2.04"

#include <RadioLib.h>
#include <SPI.h>
#include <U8g2lib.h>
#include <Wire.h>
#include <Adafruit_DS248x.h>
#include <Preferences.h>

// WiFi Server for OTA updates
#include <WiFi.h>
#include <WiFiAP.h>
#include <WebServer.h>
/* INCLUDE ESP2SOTA LIBRARY */
#include <ESP2SOTA.h>

const char* ssid = "Gilboa_Sender";
const char* password = "Gilboa_Sender";

WebServer server(80);

// These are the pins for the LoRa module. The LoRa module is an SX1262, and it is connected to the microcontroller using SPI. The CS pin is used to select the LoRa module, the DIO1 pin is used for interrupts, the RST pin is used to reset the module, and the BUSY pin is used to check if the module is busy.
#define LORA_MOSI 10
#define LORA_MISO 11
#define LORA_SCK  9
#define LORA_CS   8
#define LORA_RST  12
#define LORA_BUSY 13
#define LORA_DIO1 14
#define LORA_FREQ 915.0f

// Number of 1-wire sensors
#define NUMBER_1WIRE_TEMPERATURE_SENSORS 14 ; Number of Temperature probes
#define NUMBER_1WIRE_WATER_DETECTORS 1 ; Number of Water detection sensors (DS2413)

// These are the pins for the DS2484 1-Wire master. The VEXT_CTRL_PIN is used to control power to the DS2484, and the ADC_CTRL_PIN is used to control power to the battery voltage measurement circuit.
#define VEXT_CTRL_PIN 36
#define DS248X_ADDRESS 0x18
#define DS18B20_FAMILY_CODE 0x28
#define DS18B20_CMD_CONVERT_T 0x44
#define DS18B20_CMD_MATCH_ROM 0x55
#define DS18B20_CMD_READ_SCRATCHPAD 0xBE
#define DS18B20_CMD_SEARCH_ROM 0xF0

// These are the two water detection sensors. They work by having an open wire and an open ground wire next to each other at the bottom of the vinyl tube. When water is present, it creates a conductive path between the two wires, which can be detected by the microcontroller.
#define DS2413_FAMILY_CODE 0x3A
#define DS2413_CMD_READ 0xF5

// Battery voltage measurement
#define BATTERY_PIN 1
#define ADC_CTRL_PIN 37
#define BATTERY_SAMPLES 20

// <<< OLED ACTIVE SWITCH >>>
#define OLED_ACTIVE_PIN 4          // Pull to 3 volt = OLED ON
bool oledCurrentlyActive = false;

// <<< Debug Mode - GPIO 2 - high to stay awake >>>
#define Debug_Mode_PIN 2  // GPIO pin for Debug Mode Deep Sleep interupt
#define Debug_State_PIN 7 // GPIO pin to indicate Debug State HIGH=Debug Mode
bool hardwareDebugMode = false; // Variable of the Hardware value


U8G2_SSD1306_128X64_NONAME_F_HW_I2C u8g2(U8G2_R0, 21);
SX1262 LoRa = new Module(LORA_CS, LORA_DIO1, LORA_RST, LORA_BUSY);
Adafruit_DS248x ds248x;

Preferences prefs;

uint8_t roms[14][8];
uint8_t ds2413Rom[8];                 // Single DS2413 water detect ROM
bool hasDS2413 = false;               // Flag: do we have a DS2413?

float Sender_temp_farenheit = 0.0f;   // Sender CPU temperature in Fahrenheit
float batteryV = 0.0f;                        // Battery voltage

float temperatures[14];
String water_bottom_detected = "N/A"; // "N/A", "Y" or "N" to indicate if water is detected at the bottom sensor
String water_top_detected = "N/A"; // "N/A", "Y" or "N" to indicate if water is detected at the top sensor
int deviceCount = 0;
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

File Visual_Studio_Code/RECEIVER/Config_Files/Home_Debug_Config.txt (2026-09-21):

ESP32_NVS_BACKUP_V1
graph.minY=32.000000
graph.maxY=90.000000
email.recipient_email=jeffklopping@gmail.com
recipients.email0=jeffklopping@gmail.com
recipients.email1=
recipients.email2=
recipients.email3=
recipients.email4=
recipients.email5=
sender.email=GilboaWaterTemp@gmail.com
sender.password=efocbnzvxhcfwngx
post.url=http://jsonplaceholder.typicode.com/test
operator.aux_sleep=0
operator.oled_flag=0
operator.debug_flag=0
operator.watchdog_en=1
rom_table.0=28 6E C0 B2 00 00 00 7A
rom_table.1=28 BE 6D B2 00 00 00 61
rom_table.2=28 4D 21 7B 00 00 00 28
rom_table.3=28 ED A2 7B 00 00 00 F1
rom_table.4=28 D3 17 BA 00 00 00 24
rom_table.5=28 AF D9 B2 00 00 00 5D
rom_table.6=
rom_table.7=
rom_table.8=
rom_table.9=
rom_table.10=
rom_table.11=
rom_table.12=
rom_table.13=
dst.mode=1
ESP32_NVS_BACKUP_END

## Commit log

2026-07-08 Initial project structure
    [Barbed_End_Cap_With_Hole.FCStd, Receiver.FCStd, Sender Case.FCStd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]
2026-07-08 Fixed pointer to firmware.bin
    [main.cpp]
2026-07-08 Fixed the missing lines
    [main.cpp]
2026-07-09 Added Watchdog monitor to Receiver. Moved the "D" message before the power up of the 1-wire board.
2026-07-15 Cleaned up the Watchdog on t/c and LORA fails
    [main.cpp]
2026-07-16 Modified the comm failure messages.
    [main.cpp]
2026-07-28 Add WiFi connection setup to flowchart
2026-08-02 Update help flowchart to print commands to Telegram
2026-08-02 Update transmit packet node to use double brackets
2026-08-02 Fix formatting of flowchart node in ProcessTask.mmd
2026-08-02 Update flowchart to use double brackets for tasks
2026-08-06 Reset ESP32 on a LoRa failure on setup.
    [main.cpp]
2026-08-06 Fixed the OTA on the sender.
    [main.cpp]
2026-09-16 Added changes to turn off the display, and to added code to fix the not connecting to the wifi.
    [Gilboa_Config.txt, Home_Debug_Config.txt, Receiver-Back with Fan.3mf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]
2026-09-16 Fixed the no wifi connect
    [main.cpp]
2026-09-16 Fix for not connecting to wifi
    [main.cpp]
2026-09-16 Save current work
2026-09-17 Auto: stage and commit from VSCode
2026-09-21 Added Daylight savings time to time on status command
    [Gilboa_Config.txt, Home_Debug_Config.txt]
2026-09-22 Reverted back to no echo on terminal commands
    [main.cpp]
2026-09-27 modified documents and Kicad drawing
    [Sender_Receiver.kicad_sch]
2026-10-04 Fixed UTC Time and Date read, Added /_HISTORY
    [main.cpp]
2026-10-05 Stop tracking KiCAD history
2026-10-07 Added diag. to OLED on power up which WiFi is being searched
2026-10-18 Added trace improvements
